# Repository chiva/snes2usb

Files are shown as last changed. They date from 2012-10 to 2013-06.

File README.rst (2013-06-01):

snes2usb
========

A SNES game controller to USB converter.

Now you can use the reliable, long-lasting SNES controller with your computer games and enjoy that retro-feeling!





The objective of this project is to achieve the smallest and cheapest SNES gamepad to usb converter with the most common and easy to get components.

Instructions
------------

The converter is compatible with Windows, Linux and Mac OS, and becasuse it makes use of the standard USB HID protocol, no special drivers are needed, just plug & play.

If the game is not compatible with gamepads, you can use some of the gamepad to keyboard mappers, such as joytokey_ (Windows), qjoypad_ (Linux), enjoy_ (Mac OS).

.. _joytokey: http://www-en.jtksoft.net/
.. _qjoypad: http://qjoypad.sourceforge.net/
.. _enjoy: http://abstractable.net/enjoy/

Firmware
--------

Firmware has been developed using the latest V-USB and avr-gcc version available at the moment under Ubuntu.

The hex file the ATtiny45 requires to work is already compiled and stored inside the ``firmware`` folder, it's called ``main.hex``.

To download the firmware to the target, you should have at least ``avrdude`` installed in any platform, to install them under Ubuntu::

    $ sudo apt-get install avrdude

One of the cheapest programmers os the USBasp, but if you have a different one, please modify the avrdude line to suit your needs.

Now you can download the firmware to the target issuing::

    $ avrdude -c usbasp -p attiny45 -U flash:w:main.hex:i

PCB Board
---------

The board files under the ``schematic`` folder have been designed using DipTrace_. PDF with schematic and gerbers have been exported so there is no need to use the software, unless you want to modify them.





All parts are standard and common, they could be found on eBay at the time of the writing, that way, specialized distributors with high shipping costs can be avoided.

============  ========  =============  ========
Description   Value     Pad            Quantity
============  ========  =============  ========
uController   ATtiny45  SOIC           1
Resistor      68 Ohm    0805           2
Resistor      1.5 kOhm  0805           1
Capacitor     4.7 uF    0805           1
Diode                   DO-214AC(SMA)  2
USB Cable     1.5~2m                   1
============  ========  =============  ========

.. _DipTrace: http://www.diptrace.com/

Thanks to
---------

Based and improved from source code found at:
http://www.instructables.com/id/USB-SNES-Controller/

Special thanks to: andreq, timeblade0 and blackowaya.

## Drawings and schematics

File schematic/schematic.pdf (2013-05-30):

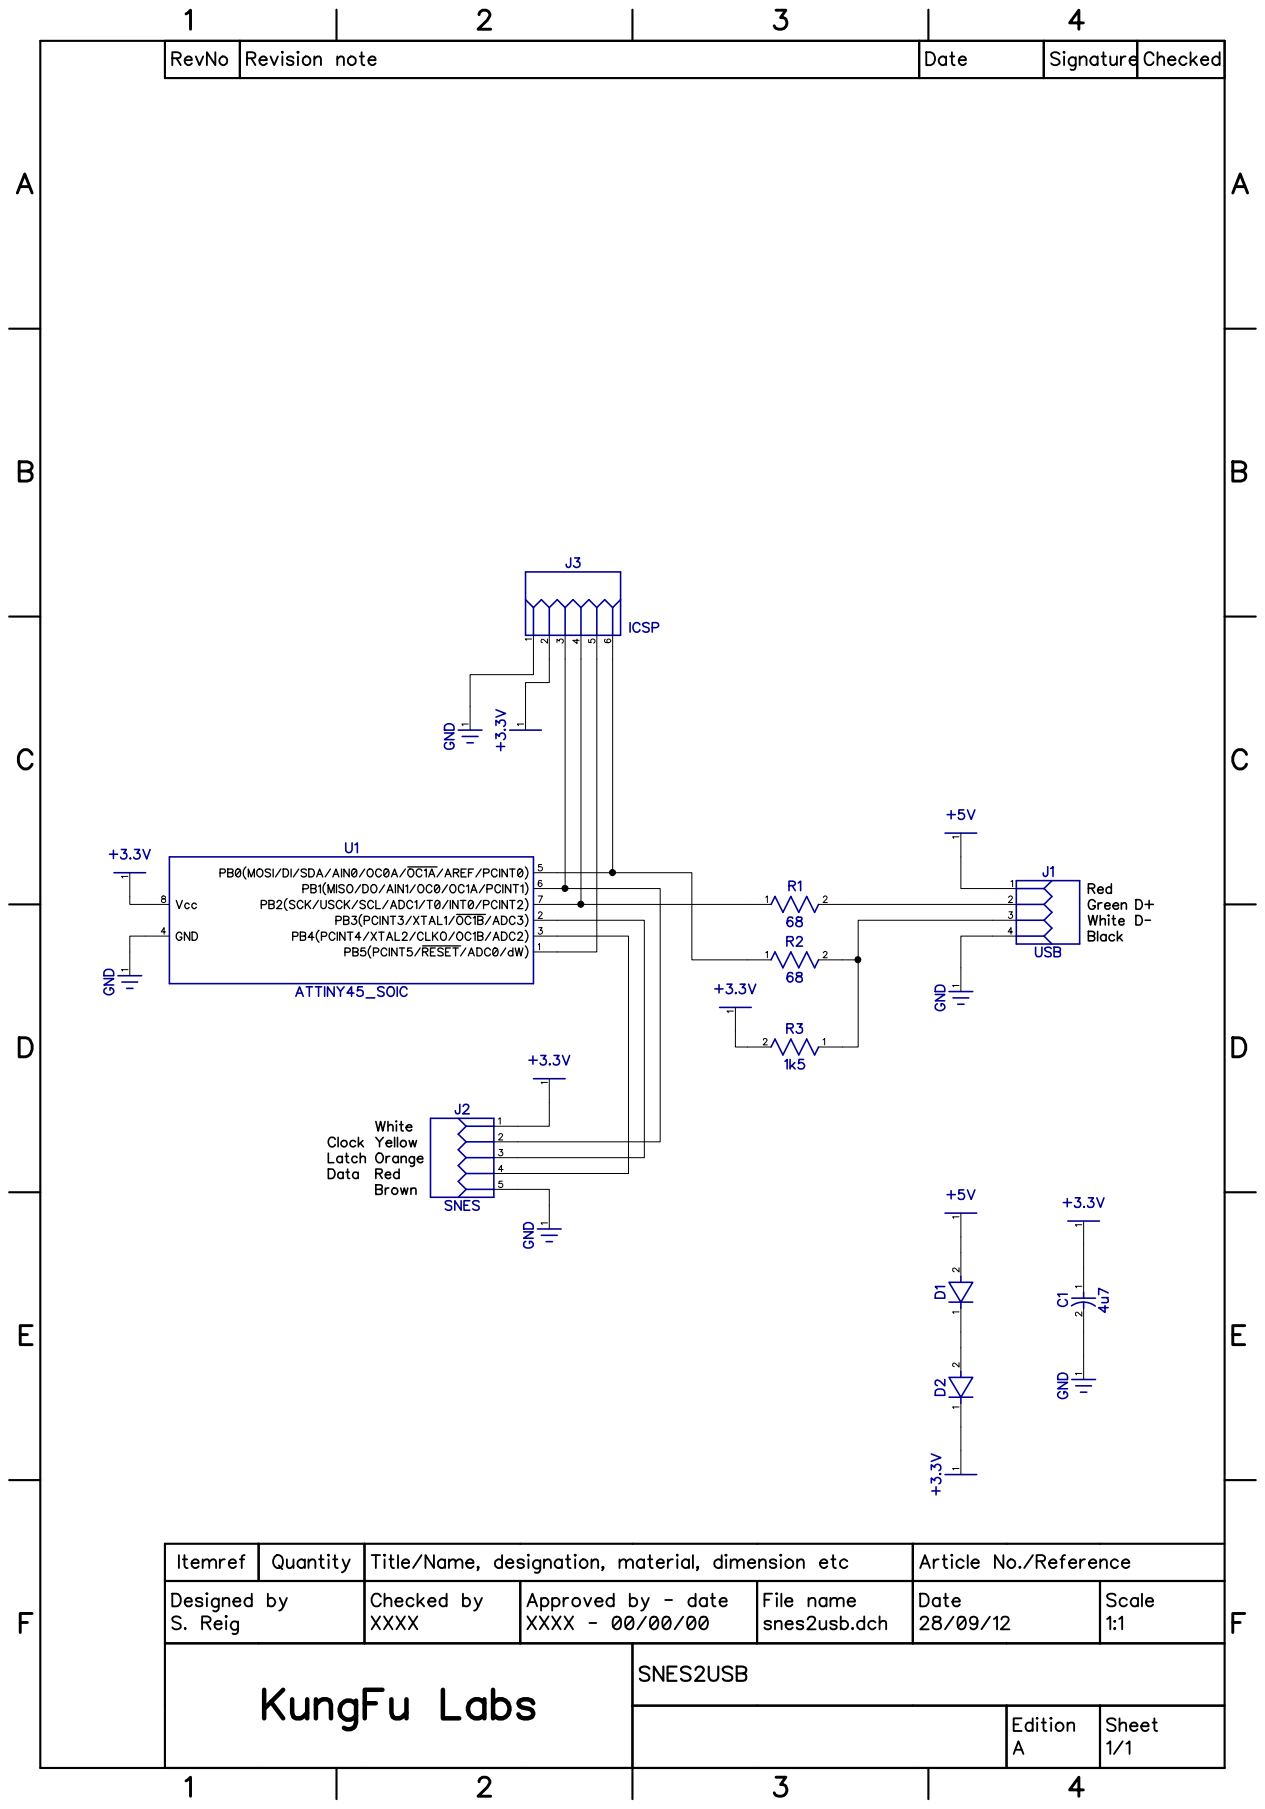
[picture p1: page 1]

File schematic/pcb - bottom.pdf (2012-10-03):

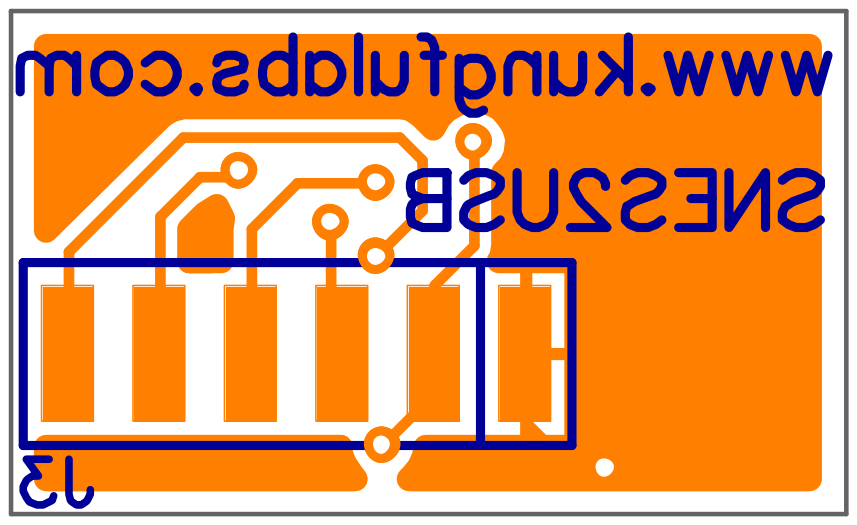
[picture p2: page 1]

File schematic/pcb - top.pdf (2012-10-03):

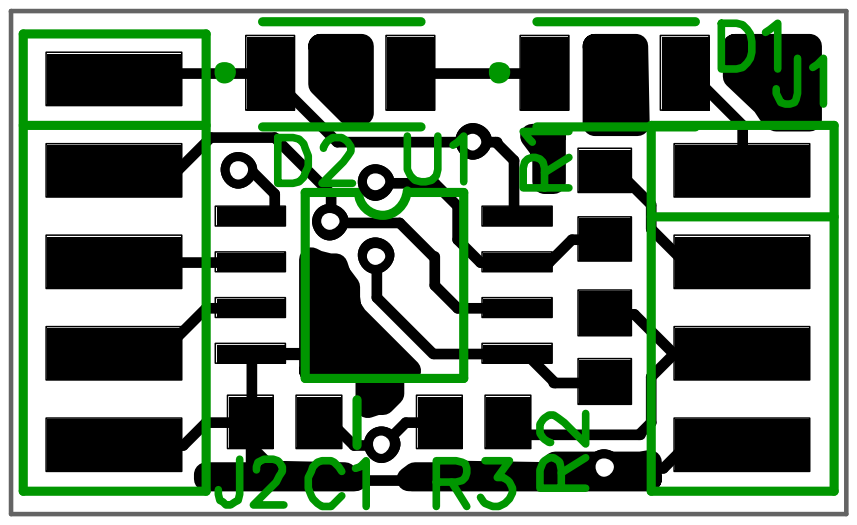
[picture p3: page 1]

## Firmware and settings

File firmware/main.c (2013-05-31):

#include <avr/io.h>
#include <avr/wdt.h>
#include <avr/interrupt.h>
#include <avr/pgmspace.h>
#include <util/delay.h>

#include "usbdrv.h"

/* Pin assignment:
 * 
 * PB0 (5) = D- (2 ws)
 * PB2 (7) = D+ (3 gn)
 * 
 * PB1 (6) = CLOCK (4)
 * PB3 (2) = LATCH (3)
 * PB4 (3) = DATA  (2)
*/

#define SNES_B       1
#define SNES_Y       2
#define SNES_SELECT  3
#define SNES_START   4
#define SNES_A       5
#define SNES_X       6
#define SNES_L       7
#define SNES_R       8

const char snesLatch = 1<<PB3;
const char snesClock = 1<<PB1;
const char snesData  = 1<<PB4;
// Customize the order in which buttons will be reported
char buttonOrder[]   = {SNES_X, SNES_A, SNES_B, SNES_Y,
                       SNES_L, SNES_R, SNES_SELECT, SNES_START};

static inline void snesLatchLow()  { PORTB &= ~snesLatch; }
static inline void snesLatchHigh() { PORTB |= snesLatch; }
static inline void snesClockLow()  { PORTB &= ~snesClock; }
static inline void snesClockHigh() { PORTB |= snesClock; }
static inline unsigned char snesGetData()   { return PINB & snesData; }

struct{
    unsigned char x;
    unsigned char y;
    unsigned char buttons;
}reportBuffer;                   /* buffer for HID reports */

static unsigned char lastRead[2];
static unsigned char lastReported[2];
static unsigned char idleRate;           /* in 4 ms units */

static void readSNES(void);
static char changedSNES(void);

const PROGMEM char usbHidReportDescriptor[USB_CFG_HID_REPORT_DESCRIPTOR_LENGTH] = { /* USB report descriptor */
    0x05, 0x01,        // USAGE_PAGE (Generic Desktop)
    0x09, 0x05,        // USAGE (Game Pad)
    0xa1, 0x01,        // COLLECTION (Application)
    0x09, 0x01,        //   USAGE (Pointer)
    0xa1, 0x00,        //   COLLECTION (Physical)
    0x09, 0x30,        //     USAGE (X)
    0x09, 0x31,        //     USAGE (Y)
    0x15, 0x00,        //     LOGICAL_MINIMUM (0)
    0x26, 0xff, 0x00,  //     LOGICAL_MAXIMUM (255)
    0x75, 0x08,        //     REPORT_SIZE (8)
    0x95, 0x02,        //     REPORT_COUNT (2)
    0x81, 0x02,        //     INPUT (Data,Var,Abs)
    0xc0,              //   END_COLLECTION
    0x05, 0x09,        //   USAGE_PAGE (Button)
    0x19, 0x01,        //   USAGE_MINIMUM (Button 1)
    0x29, 0x08,        //   USAGE_MAXIMUM (Button 8)
    0x15, 0x00,        //   LOGICAL_MINIMUM (0)
    0x25, 0x01,        //   LOGICAL_MAXIMUM (1)
    0x75, 0x01,        //   REPORT_SIZE (1)
    0x95, 0x08,        //   REPORT_COUNT (8)
    0x81, 0x02,        //   INPUT (Data,Var,Abs)
    0xc0               // END_COLLECTION
};

static void readSNES(void) {
    // Emulate SNES gamepad protocol to read the status of the buttons
    // http://www.gamefaqs.com/snes/916396-snes/faqs/5395
    unsigned char i=16, tmp=0;

    snesLatchHigh();
    _delay_us(12);
    snesLatchLow();

    while(i) {
        i--;

        _delay_us(6);
        snesClockLow();
        
        tmp <<= 1;	
        if(!snesGetData()) tmp++; 

        _delay_us(6);		
        snesClockHigh();

        if(i == 8) lastRead[0] = tmp;
    }
    lastRead[1] = tmp;
}

static char changedSNES(void) {
    if(lastRead[0] == lastReported[0] &&
       lastRead[1] == lastReported[1]) return 0;
    return 1;
}

static void buildReport(void) {
    char x, y;
    unsigned char lrcb1, lrcb2, button, i, temp, buttonNew=0;

    lastReported[0] = lrcb1 = lastRead[0];  // B,Y,Select,Start,Up,Down,Left,Right
    lastReported[1] = lrcb2 = lastRead[1];  // A,X,L,R,-,-,-,-

    y = x = 128;
    if(lrcb1 & 0x01) x = 255;
    if(lrcb1 & 0x02) x = 0;
    if(lrcb1 & 0x04) y = 255;
    if(lrcb1 & 0x08) y = 0;

    // Discard axis info and put 8 buttons state in a byte
    button = (lrcb1 & 0xF0) | (lrcb2 >> 4);

    // Order the buttons as stated at the beginning
    for(i=0; i<8; i++) {
        temp = button & (1<<((8-buttonOrder[i])));  // Take the state of the button
        temp >>= 8-buttonOrder[i];                  // Bring it to the first bit
        temp <<= i;                                 // Put it at the desired bit
        buttonNew |= temp;
    }

    reportBuffer.x = x;
    reportBuffer.y = y;
    reportBuffer.buttons = buttonNew;
}

usbMsgLen_t usbFunctionSetup(unsigned char data[8])
{
    usbRequest_t *rq = (void *)data;

    /* The following requests are never used. But since they are required by
     * the specification, we implement them in this example.
     */
    if((rq->bmRequestType & USBRQ_TYPE_MASK) == USBRQ_TYPE_CLASS){    /* class request type */
        if(rq->bRequest == USBRQ_HID_GET_REPORT){  /* wValue: ReportType (highbyte), ReportID (lowbyte) */
            /* we only have one report type, so don't look at wValue */
            usbMsgPtr = (void *)&reportBuffer;
            return sizeof(reportBuffer);
        }else if(rq->bRequest == USBRQ_HID_GET_IDLE){
            usbMsgPtr = &idleRate;
            return 1;
        }else if(rq->bRequest == USBRQ_HID_SET_IDLE){
            idleRate = rq->wValue.bytes[1];
        }
    }else{
        /* no vendor specific requests implemented */
    }
    return 0;   /* default for not implemented requests: return no data back to host */
}

// Called by V-USB after device reset
// Calibrate RC clock with the 1ms frame on USB reset
void hadUsbReset() {
    unsigned char step = 128;
    unsigned char trialValue = 0, optimumValue;
    int   x, optimumDev, targetValue = (unsigned)(1499 * (double)F_CPU / 10.5e6 + 0.5);
 
    /* do a binary search: */
    do{
        OSCCAL = trialValue + step;
        x = usbMeasureFrameLength();    // proportional to current real frequency
        if(x < targetValue)             // frequency still too low
            trialValue += step;
        step >>= 1;
    }while(step > 0);
    /* We have a precision of +/- 1 for optimum OSCCAL here */
    /* now do a neighborhood search for optimum value */
    optimumValue = trialValue;
    optimumDev = x; // this is certainly far away from optimum
    for(OSCCAL = trialValue - 1; OSCCAL <= trialValue + 1; OSCCAL++){
        x = usbMeasureFrameLength() - targetValue;
        if(x < 0)
            x = -x;
        if(x < optimumDev){
            optimumDev = x;
            optimumValue = OSCCAL;
        }
    }
    OSCCAL = optimumValue;
}

int __attribute__((noreturn)) main(void) {
    unsigned char i;

    wdt_enable(WDTO_1S);
    /* Even if you don't use the watchdog, turn it off here. On newer devices,
     * the status of the watchdog (on/off, period) is PRESERVED OVER RESET!
     */
    /* RESET status: all port bits are inputs without pull-up.
     * That's the way we need D+ and D-. Therefore we don't need any
     * additional hardware initialization.
     */

    //Init SNES-Controller
    DDRB = snesLatch | snesClock;

    usbInit();
    usbDeviceDisconnect();  /* enforce re-enumeration, do this while interrupts are disabled! */
    i = 0;
    while(--i){             /* fake USB disconnect for > 250 ms */
        wdt_reset();
        _delay_ms(1);
    }
    usbDeviceConnect();
    sei();

    for(;;) { //main event loop
        wdt_reset();
        usbPoll();
        readSNES();
        // Only report if buttons state have changed
        if(usbInterruptIsReady() && changedSNES()){
            buildReport();
            usbSetInterrupt((void *)&reportBuffer, sizeof(reportBuffer));
        }
    }
}

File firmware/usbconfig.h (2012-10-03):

/* Name: usbconfig.h
 * Project: V-USB, virtual USB port for Atmel's(r) AVR(r) microcontrollers
 * Author: Christian Starkjohann
 * Creation Date: 2005-04-01
 * Tabsize: 4
 * Copyright: (c) 2005 by OBJECTIVE DEVELOPMENT Software GmbH
 * License: GNU GPL v2 (see License.txt), GNU GPL v3 or proprietary (CommercialLicense.txt)
 * This Revision: $Id$
 */

#ifndef __usbconfig_h_included__
#define __usbconfig_h_included__

/*
General Description:
This file is an example configuration (with inline documentation) for the USB
driver. It configures V-USB for USB D+ connected to Port D bit 2 (which is
also hardware interrupt 0 on many devices) and USB D- to Port D bit 4. You may
wire the lines to any other port, as long as D+ is also wired to INT0 (or any
other hardware interrupt, as long as it is the highest level interrupt, see
section at the end of this file).
+ To create your own usbconfig.h file, copy this file to your project's
+ firmware source directory) and rename it to "usbconfig.h".
+ Then edit it accordingly.
*/

/* ---------------------------- Hardware Config ---------------------------- */

#define USB_CFG_IOPORTNAME      B
/* This is the port where the USB bus is connected. When you configure it to
 * "B", the registers PORTB, PINB and DDRB will be used.
 */
#define USB_CFG_DMINUS_BIT      0
/* This is the bit number in USB_CFG_IOPORT where the USB D- line is connected.
 * This may be any bit in the port.
 */
#define USB_CFG_DPLUS_BIT       2
/* This is the bit number in USB_CFG_IOPORT where the USB D+ line is connected.
 * This may be any bit in the port. Please note that D+ must also be connected
 * to interrupt pin INT0! [You can also use other interrupts, see section
 * "Optional MCU Description" below, or you can connect D- to the interrupt, as
 * it is required if you use the USB_COUNT_SOF feature. If you use D- for the
 * interrupt, the USB interrupt will also be triggered at Start-Of-Frame
 * markers every millisecond.]
 */
#define USB_CFG_CLOCK_KHZ       (F_CPU/1000)
/* Clock rate of the AVR in kHz. Legal values are 12000, 12800, 15000, 16000,
 * 16500, 18000 and 20000. The 12.8 MHz and 16.5 MHz versions of the code
 * require no crystal, they tolerate +/- 1% deviation from the nominal
 * frequency. All other rates require a precision of 2000 ppm and thus a
 * crystal!
 * Since F_CPU should be defined to your actual clock rate anyway, you should
 * not need to modify this setting.
 */
#define USB_CFG_CHECK_CRC       0
/* Define this to 1 if you want that the driver checks integrity of incoming
 * data packets (CRC checks). CRC checks cost quite a bit of code size and are
 * currently only available for 18 MHz crystal clock. You must choose
 * USB_CFG_CLOCK_KHZ = 18000 if you enable this option.
 */

/* ----------------------- Optional Hardware Config ------------------------ */

/* #define USB_CFG_PULLUP_IOPORTNAME   D */
/* If you connect the 1.5k pullup resistor from D- to a port pin instead of
 * V+, you can connect and disconnect the device from firmware by calling
 * the macros usbDeviceConnect() and usbDeviceDisconnect() (see usbdrv.h).
 * This constant defines the port on which the pullup resistor is connected.
 */
/* #define USB_CFG_PULLUP_BIT          4 */
/* This constant defines the bit number in USB_CFG_PULLUP_IOPORT (defined
 * above) where the 1.5k pullup resistor is connected. See description
 * above for details.
 */

/* --------------------------- Functional Range ---------------------------- */
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
